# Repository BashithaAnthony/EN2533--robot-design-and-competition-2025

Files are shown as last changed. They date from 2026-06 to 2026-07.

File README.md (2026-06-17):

# EN2533 – Robot Design and Competition 2025

## Overview

As my first complete robotics project, this robot was designed from the ground up to autonomously navigate a multi-stage competition arena, perform object manipulation tasks, interpret environmental information, and complete a series of engineering challenges without human intervention.

The project required the integration of mechanical design, embedded systems, sensor fusion, control systems, and autonomous decision-making into a single robotic platform capable of completing all competition tasks reliably and efficiently.

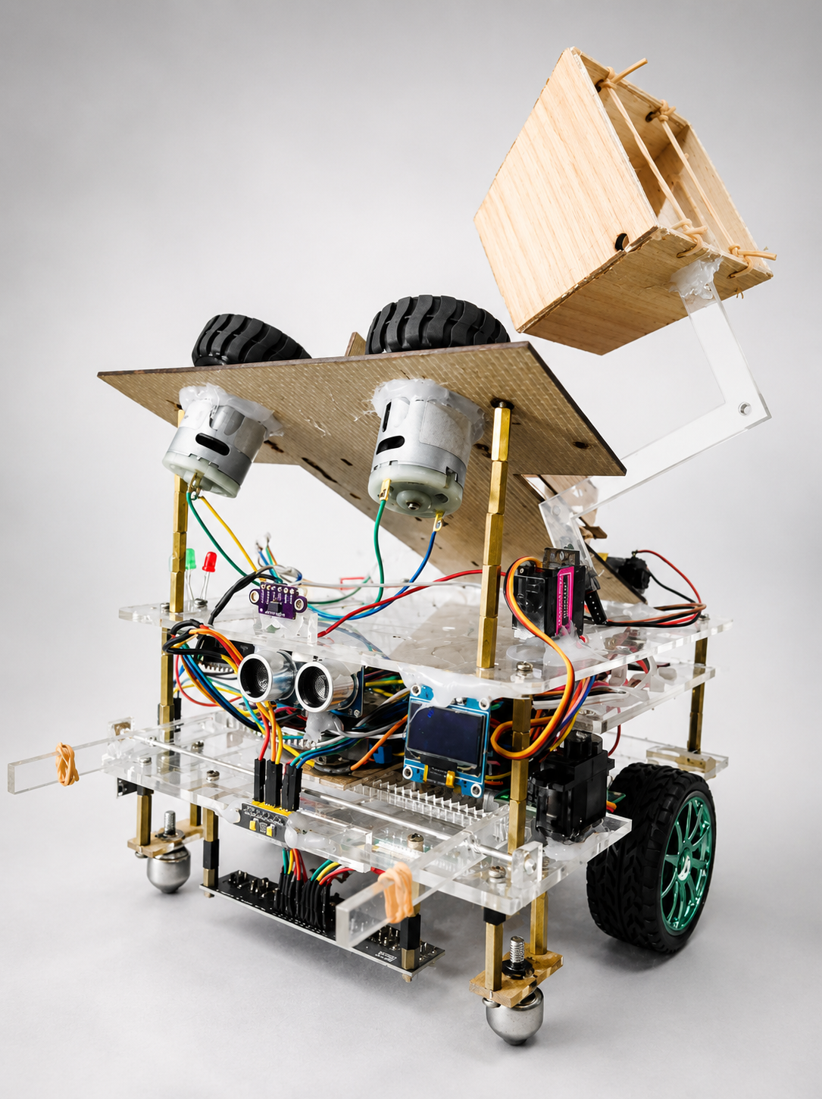
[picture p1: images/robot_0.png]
Robot Overview


## Competition Tasks

The robot was designed to complete the following six autonomous challenges:

### 1. Grid Navigation and Box Pick-and-Place
- Navigate a structured grid environment.
- Identify target locations.
- Pick up and transport boxes.
- Place objects accurately at designated positions.

### 2. Ramp Alignment, Ascending and Descending
- Set up the ramp.
- Maintain stability while climbing.
- Perform controlled descent without losing localization.

### 3. Barcode Reading
- Detect and scan barcodes placed on the arena floor.
- Decode barcode information.
- Use the extracted information for next task execution.

### 4. Circular Wall Following and Ball Collection
- Follow a circular wall using distance sensing.
- Maintain a consistent offset from the wall.
- Locate and collect balls while following the inner circular wall

### 5. Dashed Line Following and Pendulum Crossing
- Detect and follow discontinuous line markings.
- Handle temporary loss of line information.
- Safely navigate through a moving pendulum obstacle.

### 6. Ball Shooting Mechanism
- Position accurately at the target zone.
- Aim and launch collected balls toward designated targets.

## Hardware Components

### Main Controller
- Arduino Mega 2560

### Actuation Systems
- DC Motors with Quadrature Encoders
- Stepper Motors
- Servo Motors

### Sensors
- Time-of-Flight (ToF) Distance Sensors
- Ultrasonic Sensors
- Infrared (IR) Sensors
- Color Sensors

## Technical Highlights

- Fully autonomous operation
- Multi-sensor integration and sensor fusion
- Encoder-based motion control
- Closed-loop navigation
- Autonomous object manipulation
- Real-time obstacle detection and avoidance
- Modular software architecture
- Embedded control system development
- Mechanical system design and fabrication

## Project Status

Completed

Developed as part of the **EN2533 – Robot Design and Competition** module and demonstrated in the final competition environment.

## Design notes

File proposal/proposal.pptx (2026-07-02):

## EN2533 - Robot presentation

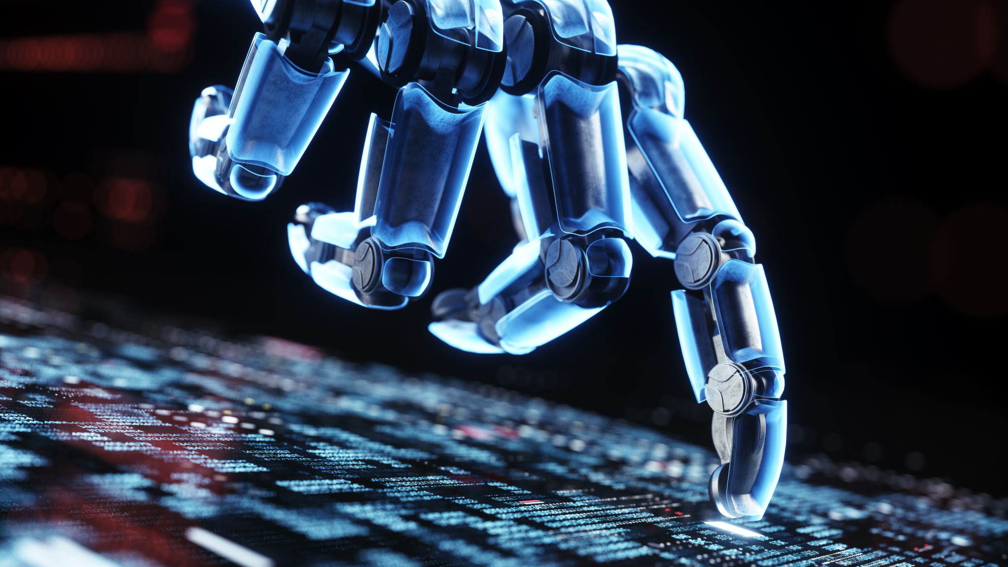
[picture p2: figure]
Robot operating a machine

TEAM HELABOTS

230045X

230140J

230697V

230730T

Anthony C.S.B.

Dharmakeerthi P.K.G.C.L.

Weerasinghe J.A.H.R.

Wijethilaka J.S.

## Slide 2

Timeline

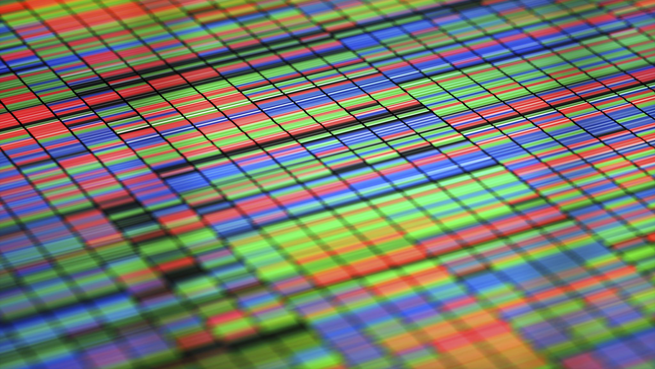
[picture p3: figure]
Vibrant multicolor checkered floor design

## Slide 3

September | | | | October
Week 1 | Week 2 | Week 3 | Week 4 | Week 5 | Week 6 | Week 7 | Week 8
Task Identification, Initial Designs | Component selection, Purchasing components | Preparation for assignment and Task evaluation | Initial Assembling | Coding and Testing | | Finalizing Assembling of the Robot

November | | | | December
Week 9 | Week 10 | Week 11 | Week 12 | Week 13 | Week 14 | Week 15 | Week 16
Preparation for mid evaluation | End Semester Examinations | | | Calibration, Testing and Debugging | | | Robot Competition

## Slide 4

Task 1 - The Labyrinth of Shadows

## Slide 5

PATH FINDING

- The robot will be placed at the position Po and it will start traversing the grid to P1 avoiding all obstacles it encounter.
- Then it will start travelling to P2 while scanning the destinations where the boxes should be placed and mapping them.
- Thereon from P2 the robot will start solving the grid while avoiding obstacles.
- When the robot encounters a box, it will grab it and start travelling to the appropriate destination through shortest available path.

- If an obstacle is encountered while travelling to the destination, the robot will map it and start travelling to the destination through the shortest path without the obstacle.

- After travelling it will drop the box there and continue travelling the grid until two boxes are placed on their respective destinations.

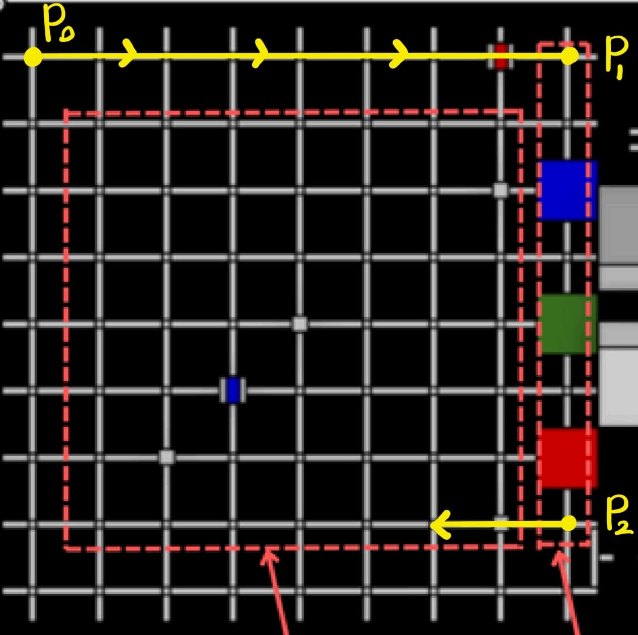
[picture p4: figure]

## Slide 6

LINE FOLLOWING

- We chose the MD0167 8-Bit Line Hunting Sensor Follower Module for line following because of its,
- Wide Detection Range
  - The module has 8 independent IR sensors arranged in a row, which provides much better coverage compared to single-sensor or 3-sensor modules.
- High Precision and Stability
  - With 8 channels, it allows fine resolution in detecting the line’s exact position.
- Simple Integration with Arduino
  - It’s fully compatible with Arduino and other microcontrollers.
- Better Performance on Different Surfaces
  - The MD0167 has built-in sensitivity adjustment, so it works well on surfaces with varying reflectivity.
- Cost-Effectiveness

8-Bit Line Hunting Sensor Follower Module for Arduino (MD0167)

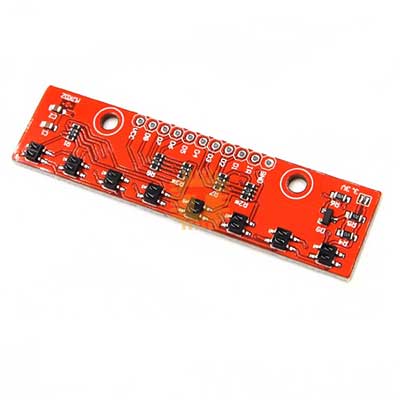
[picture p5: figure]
A red circuit board with black and red components

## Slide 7

BOX DETECTION

- We chose the HY-SRF05 Ultrasonic Sensor for obstacle and box detection and to differentiate between the boxes and the obstacles TCS34725 RGB Colour Recognition Sensor is used as boxes have their specific RGB colours.
- The HY-SRF05 Ultrasonic Sensor can measure distances from about 2 cm up to 4–5 meters with good accuracy. Compared to the common HC-SR04 sensor, the HY-SRF05 has better accuracy and stability in distance measurement. So, it provides accurate distance measurements. Also it is easy to interface with Arduino. Since it uses ultrasonic sound waves, it works equally well in dark or bright environments where optical sensors might fail.
- The TCS34725 has a high-quality RGB and clear light sensing photodiode array. The sensor includes an IR blocking filter, which removes infrared light interference. This makes color detection more accurate even under different lighting conditions. This also is well supported with Arduino libraries.

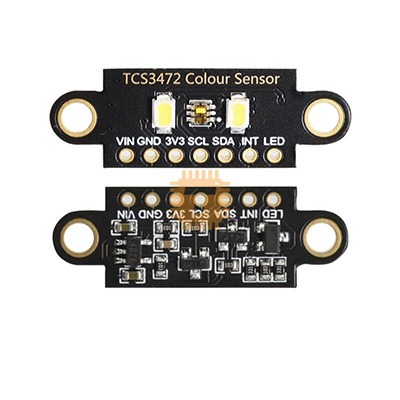
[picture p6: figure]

TCS34725 RGB colour Recognition sensor

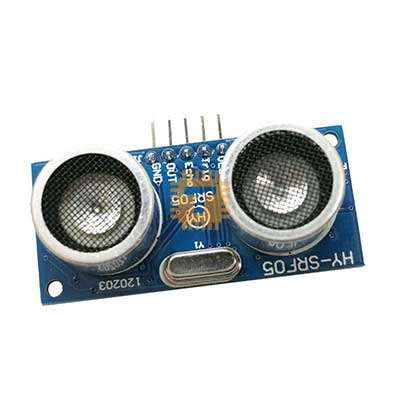
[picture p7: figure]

HY-SRF05 HC-SR05 5Pin Ultrasonic Sensor Module

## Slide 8

BOX PICKING & PLACING

- The boxes are picked from robot arm mechanism powered by MG90 Metal Wheel Servo Motor.

Why We Chose the MG90 Metal Gear Servo Motor

- High Torque for Small Size
  - The MG90 provides around 2.2 kgcm torque, which is enough to move lightweight robotic arms and small payloads.
- Metal Gears for Durability
  - Unlike plastic gear servos (e.g., SG90), the MG90 uses metal gears, making it more durable. This makes it suitable for repeated arm movements without gear damage.
- Arduino Friendly
  - Works easily with Arduino PWM libraries.

Servo Motor Metal Wheel MG90

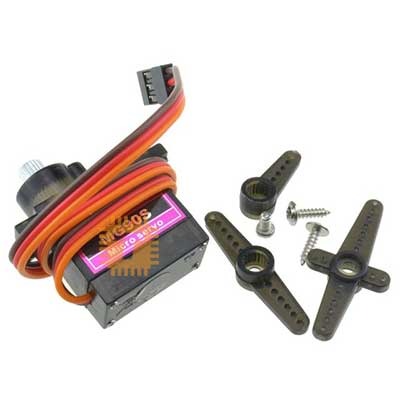
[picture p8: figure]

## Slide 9

Task 2 – The Ramp of Trials

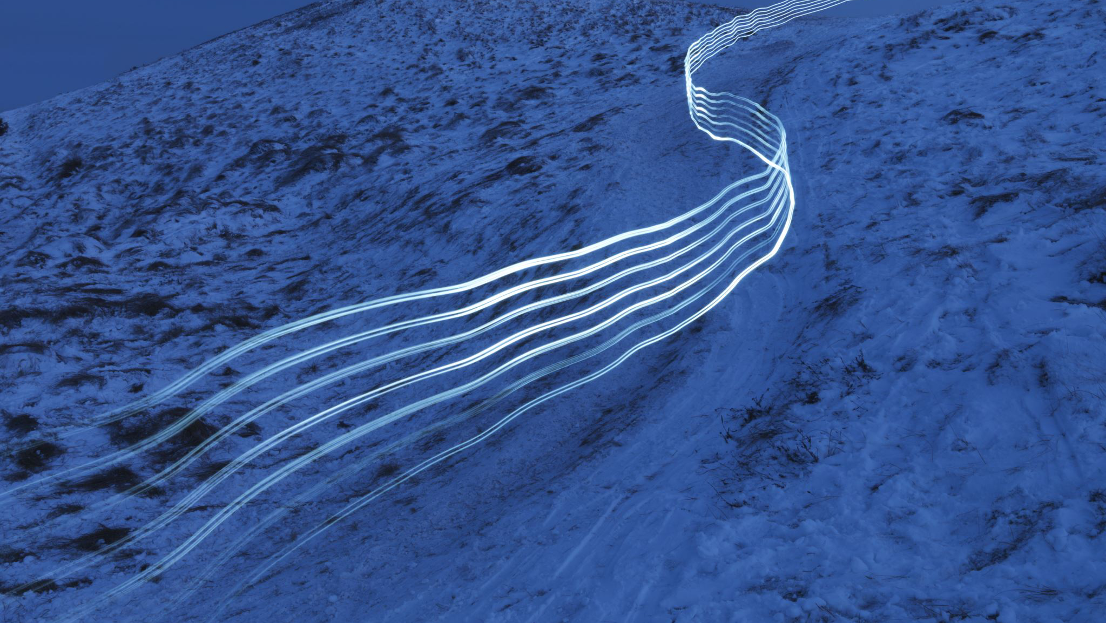
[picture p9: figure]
Smoke pattern on snow

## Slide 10

- In this task the robot will traverse through the broken lines using the IR sensor array until it finds a horizontal line and stop there.
- Using the closed front arms, it will push the box and fill the gap.
- Then the robot will comeback to the position of the horizontal line.
- After that the robot will traverse back to the starting point of the broken lines following the broken lines.
- Then it will approach the ramp and climb up and down the ramp.
- When climbing up, robot arm will be stretched towards the frontside of the robot (towards the ramp) and while climbing down, arm will be stretched towards the backside of the robot to keep the center of the gravity at a better position.

Traversing the broken lines:
The robot follow the direction of each line segment until it find the next line segment and then it will adjust the direction again.

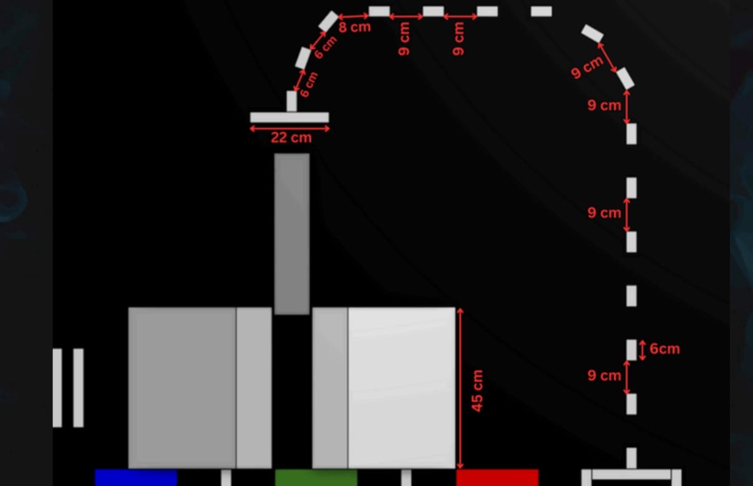
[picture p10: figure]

## Task 3 – the oracle of runes

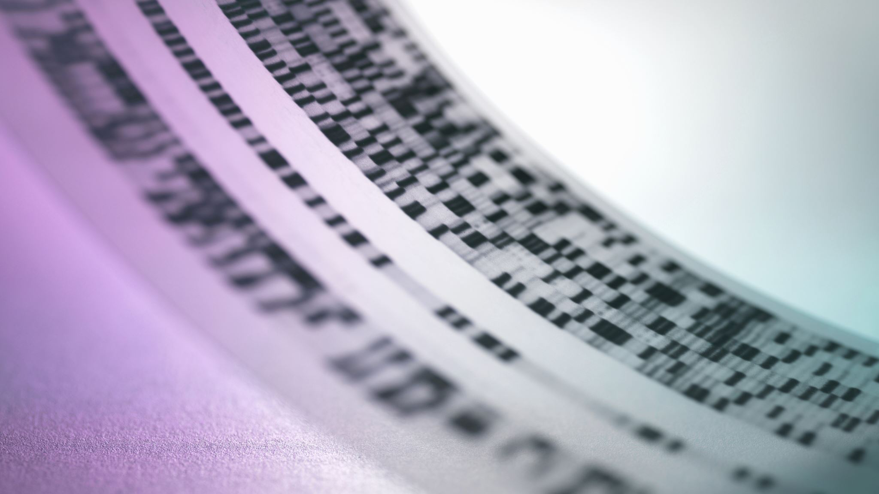
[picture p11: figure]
Autoradiogram on white paper

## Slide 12

- In the oracle of runes, the robot will come to the barcode area, and it will pass through the barcode at a constant speed while measuring the time to pass the white lines separately.

- Then it will decode the barcode and read the number and divide it by 3 and take the remainder.
- This will tell us the number of spheres we have to collect which will be one of 2,3 or 4 spheres.

- The robot will have 4 indicating LEDs to light up accordingly to show the number of spheres it should collect.

Remainder | No. of Spheres | No. of LEDs Turned on
0 | 2 | 2
1 | 3 | 3
2 | 4 | 4

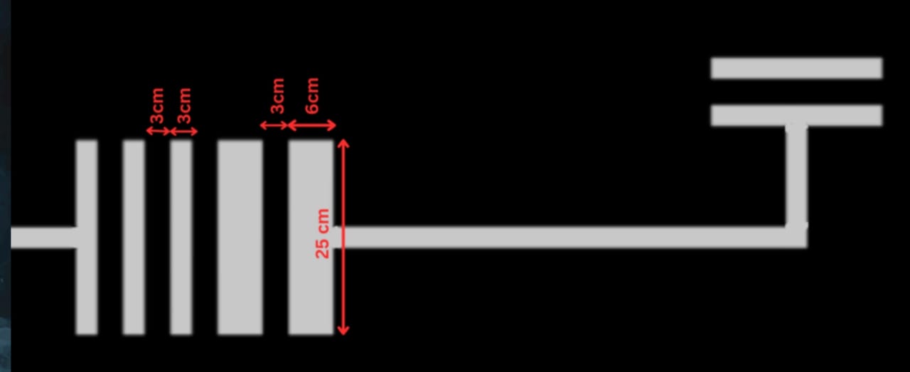
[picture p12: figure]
A white rectangular object with red text

## Task 4 – the circular fortress

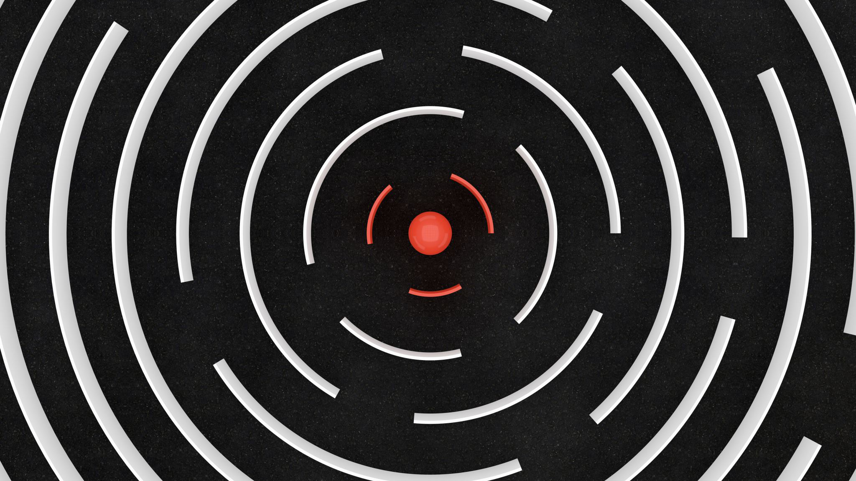
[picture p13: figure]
Top view of a labyrinth

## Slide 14

- The robot moves forward until it reaches a wall.
- Then follows the wall while maintaining a constant distance from it until it detects an opening.
- After detecting the opening, the robot makes a 180- degree U turn around the corner of the opening and continues following the wall while using its robotic arm to pick up balls and place them into a container.
- Once it reaches the opposite end, it performs another 180-degree turn around the other corner and returns to the starting position by following the wall.

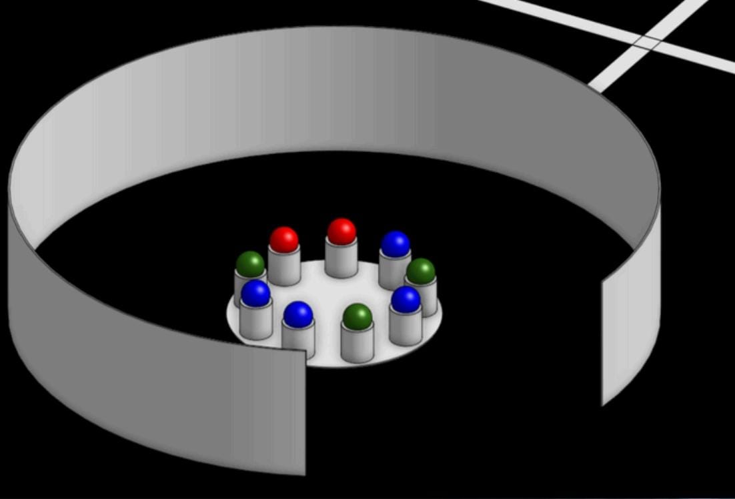
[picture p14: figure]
A circular object with several colored objects

## Task 5 – the wall of whispers & pendulum of doom

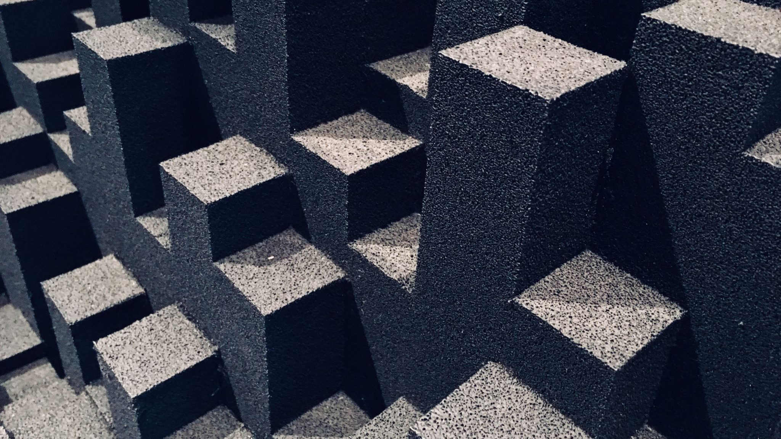
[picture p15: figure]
3D square and rectangle

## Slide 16

- This task consists of 3 major phases.
  1. Traversing the broken lines
  2. THE HIDDEN TASK
  3. Wall following & avoiding the pendulum

1.Traversing the broken
lines using IR sensor array:
Robot follow the direction of each line segment until it find the next line segment and then it will adjust the direction again.

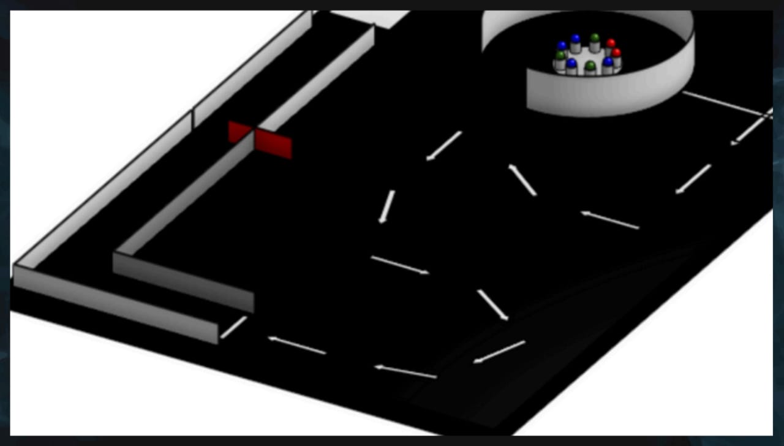
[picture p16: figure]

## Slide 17

2. Wall Following & Avoiding the Pendulum:
Using 2 Time of Flight sensors at two sides of the robot, it will go through two walls at a medium speed until it reaches the first junction and then it will move little bit slower until it detects the pendulum. Right after pendulum swings away, robot will move fast towards forward direction.

- After coming towards the end of two walls, robot will end up staying on the white square with the aid of IR sensors. After correctly positioning the robot on the square, it will turn left towards the ring of triumph.

## Task 6 – the line of destiny & the ring of triumph

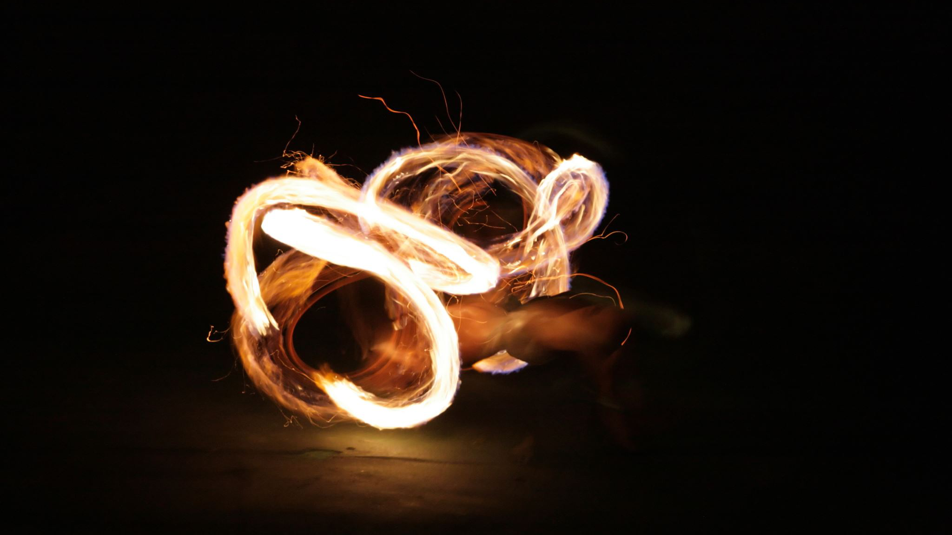
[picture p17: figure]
A light trail using fire

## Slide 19

- In this task we will try out 2 methods.

1. Method 01:
  - Balls will be shot towards the ring using two rotating motors. Using the mechanical arm, balls will be placed right in the middle of two motors.

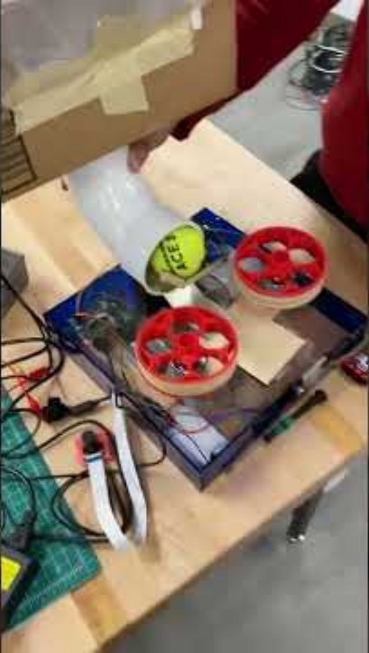
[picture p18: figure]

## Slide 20

2. Method 02:
  - Balls will be shot using a triggering mechanism as follows. In this method, there will not be any need to place the ball again because, after picking balls, they will be stored in the container where the triggering mechanism is connected right beneath the container

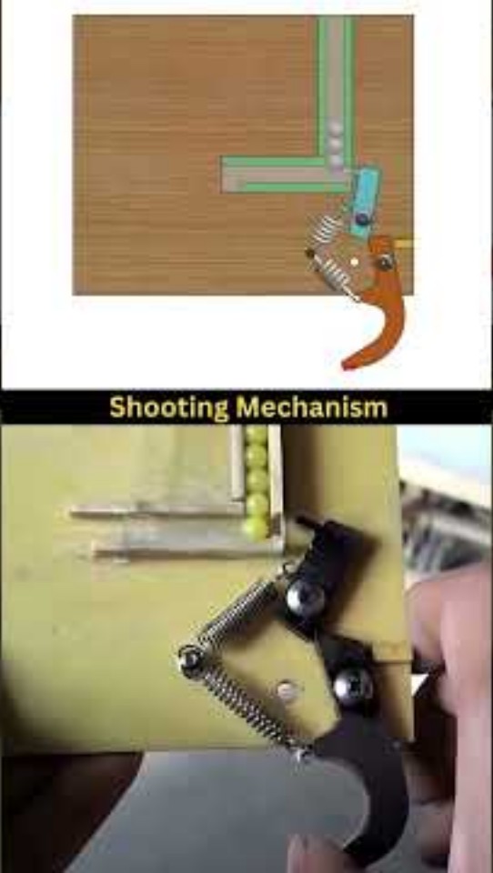
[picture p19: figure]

## The Budget

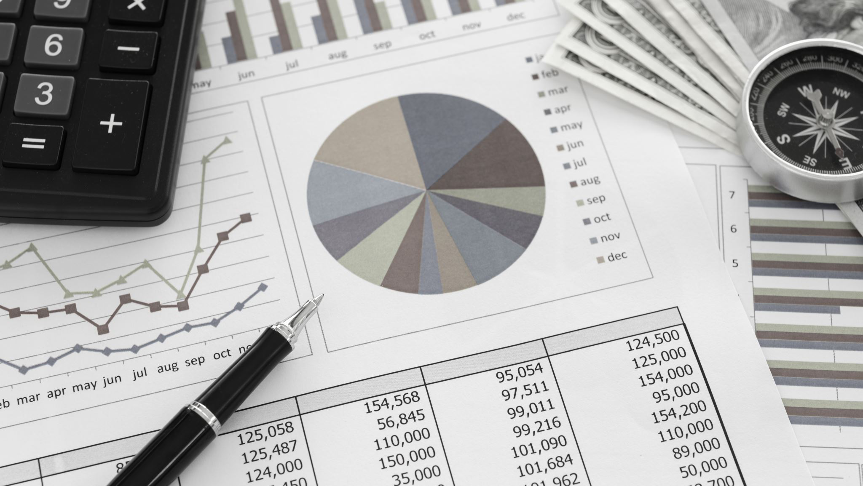
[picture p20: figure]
Calculator, pen, compass, money and a paper with graphs printed on it

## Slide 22

Component | Quantity | Unit Price (LKR) | Total (LKR)
Encoder motors | 2 | 3400 | 6800
Wheels | 2 | 100 | 200
Encoder motor driver | 1 | 320 | 320
Servo motors | 5 | 480 | 2400
Colour sensors | 3 | 760 | 2280
Buck converter | 1 | 180 | 180
Arduino mega | 1 | 4850 | 4850
Acrylic board | 1 | 1650 | 1650
IR sensor array | 1 | 480 | 480
ToF sensors | 3 | 600 | 1800
11.1V LiPo battery | 1 | 3000 | 3000
11.1V LiPo battery charger | 1 | 2500 | 2500
Ultrasonic sensor | 1 | 390 | 390
Robot arms (Materials, Laser cutting, 3D printing) | | | 3500
16 channel analog multiplexer | 1 | 450 | 450
Others | | | 750
Total | | | 31550

## Q&A

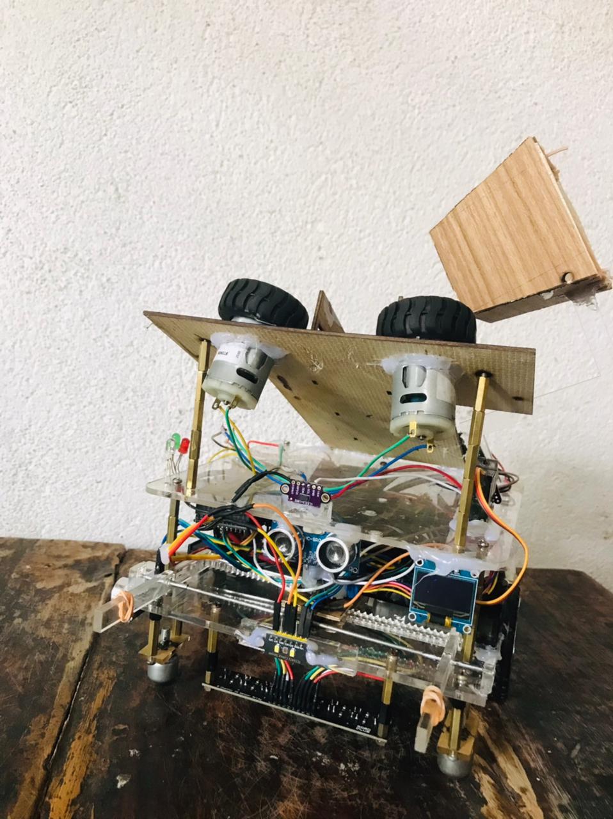
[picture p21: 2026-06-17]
images/robot_2.jpeg

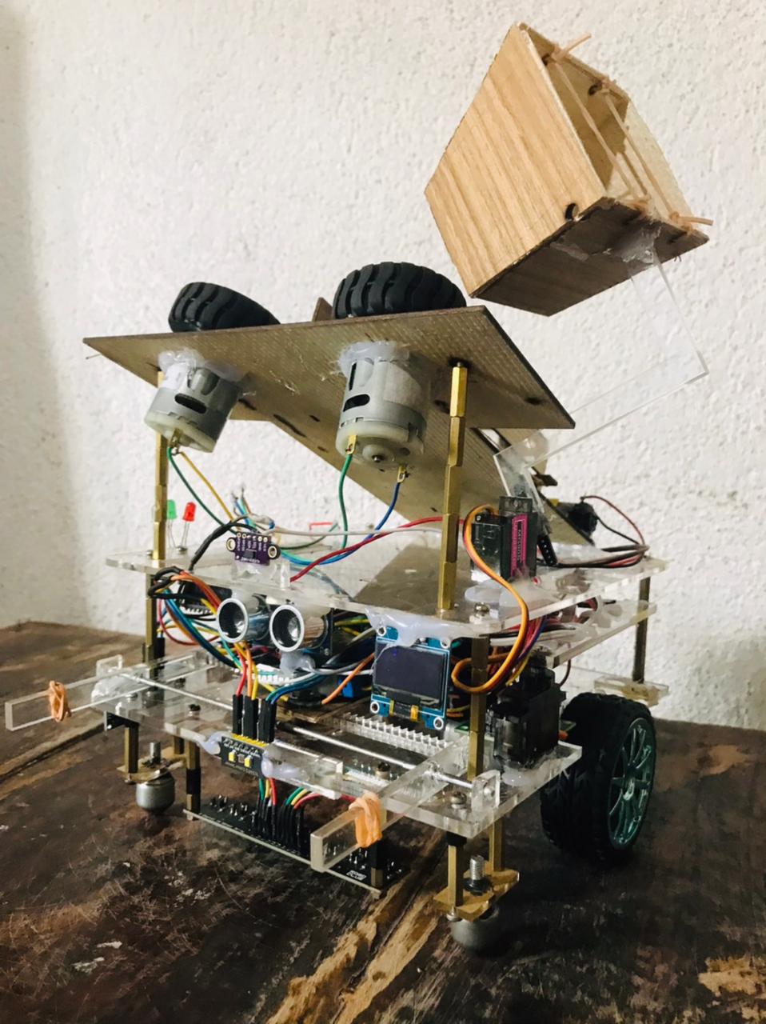
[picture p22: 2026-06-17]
images/robot_1.jpeg

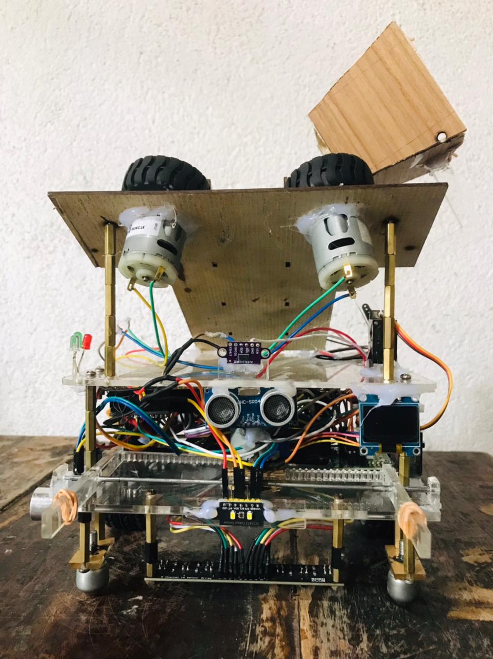
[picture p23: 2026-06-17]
images/robot_front.jpeg

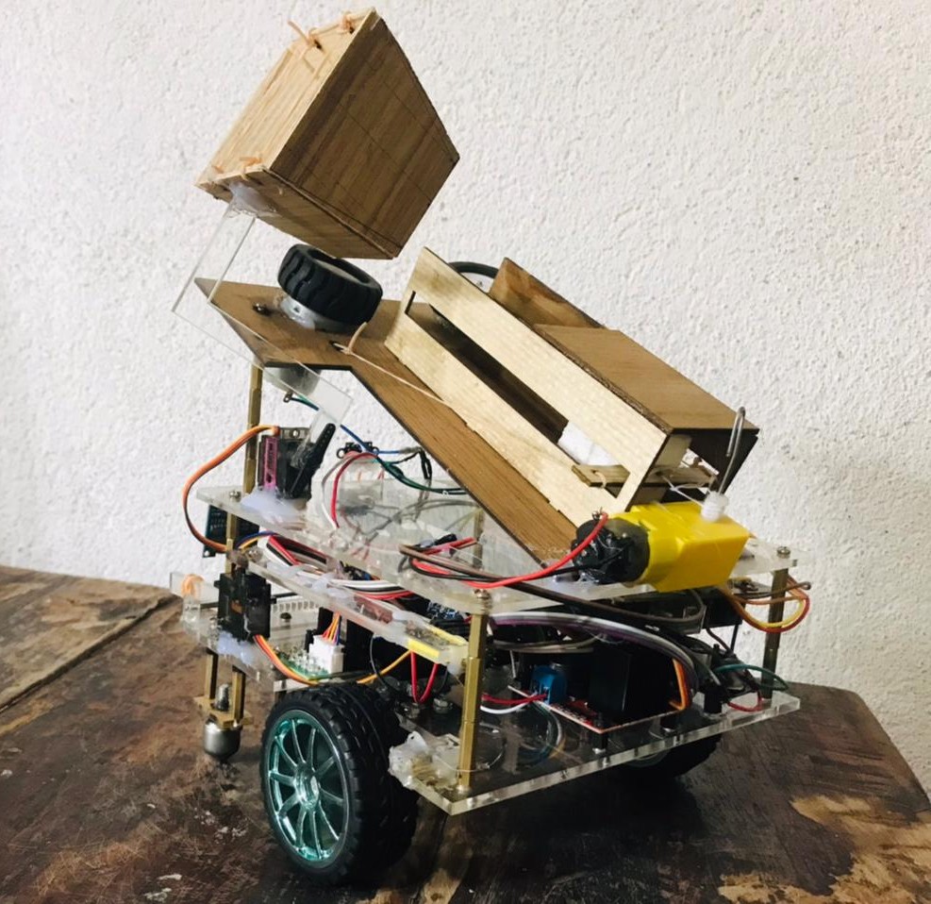
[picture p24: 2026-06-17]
images/robot_back.jpeg

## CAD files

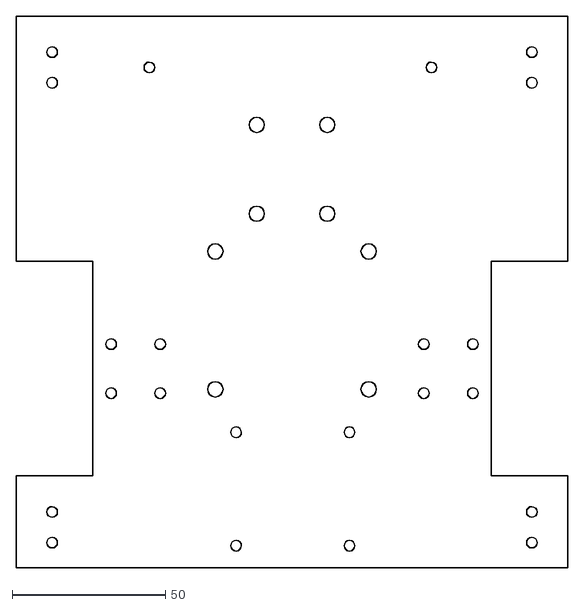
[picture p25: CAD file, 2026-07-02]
design_files/robot_platform.dxf
180.0 x 180.0

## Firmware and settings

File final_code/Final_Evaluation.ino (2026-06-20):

//--Colour Sensor and two ToF sensors--//
#include <Wire.h>
#include <VL53L0X.h>
#include <Adafruit_VL53L0X.h>
#include "Adafruit_TCS34725.h"
#include <Servo.h>
#include <Adafruit_GFX.h>
#include <Adafruit_SSD1306.h>
#include "I2Cdev.h"
#include "MPU6050_6Axis_MotionApps20.h"

//Varibles for Menu handaling
#define BUTTON_PIN 34
bool button_pushed = true;
int8_t task = 1;

//Display Object
Adafruit_SSD1306 display(128, 64, &Wire, -1);
#define SCREEN_WIDTH 128
#define SCREEN_HEIGHT 64
#define OLED_ADDR 0x3C


Servo servo1; // Colour Sensing Servo
Servo servo2; // Ball Picking Servo

//VL53L0X tof1;   // ToF on channel 5
//VL53L0X tof2;   // ToF on channel 4
// ---------- ToF SENSORS ----------
Adafruit_VL53L0X tof1;  // CH4
Adafruit_VL53L0X tof2;  // CH5

Adafruit_TCS34725 colorSensor = Adafruit_TCS34725(
  TCS34725_INTEGRATIONTIME_50MS,
  TCS34725_GAIN_4X
);

// ---------- COLOR SENSORS ----------
Adafruit_TCS34725 color1 = Adafruit_TCS34725(
  TCS34725_INTEGRATIONTIME_50MS, TCS34725_GAIN_4X);  // CH3

Adafruit_TCS34725 color2 = Adafruit_TCS34725(
  TCS34725_INTEGRATIONTIME_50MS, TCS34725_GAIN_4X);  // CH7

uint16_t dist1 = 0;
uint16_t dist2 = 0;


//------BFS parameters-----//

struct Node{
  int8_t x;
  int8_t y;
};

struct direction{
  int8_t delta_x;
  int8_t delta_y;
};

enum node_state{
  Free,
  NotKnow,
  Blocked,
  Box
};

node_state grid[9][9] = {
  {NotKnow, NotKnow, NotKnow, NotKnow, NotKnow, NotKnow, NotKnow, NotKnow, NotKnow},
  {NotKnow, NotKnow, NotKnow, NotKnow, NotKnow, NotKnow, NotKnow, NotKnow, NotKnow},
  {NotKnow, NotKnow, NotKnow, NotKnow, NotKnow, NotKnow, NotKnow, NotKnow, NotKnow},
  {NotKnow, NotKnow, NotKnow, NotKnow, NotKnow, NotKnow, NotKnow, NotKnow, NotKnow},
  {NotKnow, NotKnow, NotKnow, NotKnow, NotKnow, NotKnow, NotKnow, NotKnow, NotKnow},
  {NotKnow, NotKnow, NotKnow, NotKnow, NotKnow, NotKnow, NotKnow, NotKnow, NotKnow},
  {NotKnow, NotKnow, NotKnow, NotKnow, NotKnow, NotKnow, NotKnow, NotKnow, NotKnow},
  {NotKnow, NotKnow, NotKnow, NotKnow, NotKnow, NotKnow, NotKnow, NotKnow, NotKnow},
  {Blocked, Blocked, Blocked, Blocked, Blocked, Blocked, Blocked, Blocked, Blocked}
};

const direction directions[4] = { {0,1}, {0,-1}, {1,0}, {-1,0}}; // North, South, East, West

const Node Search_path[81] = {
  {0,0}, {1,0}, {2,0}, {3,0}, {4,0}, {5,0}, {6,0}, {7,0}, {8,0},
  {8,1}, {7,1}, {6,1}, {5,1}, {4,1}, {3,1}, {2,1}, {1,1}, {0,1},
  {0,2}, {1,2}, {2,2}, {3,2}, {4,2}, {5,2}, {6,2}, {7,2}, {8,2},
  {8,3}, {7,3}, {6,3}, {5,3}, {4,3}, {3,3}, {2,3}, {1,3}, {0,3},
  {0,4}, {1,4}, {2,4}, {3,4}, {4,4}, {5,4}, {6,4}, {7,4}, {8,4},
  {8,5}, {7,5}, {6,5}, {5,5}, {4,5}, {3,5}, {2,5}, {1,5}, {0,5},
  {0,6}, {1,6}, {2,6}, {3,6}, {4,6}, {5,6}, {6,6}, {7,6}, {8,6},
  {8,7}, {7,7}, {6,7}, {5,7}, {4,7}, {3,7}, {2,7}, {1,7}, {0,7},
  {0,8}, {1,8}, {2,8}, {3,8}, {4,8}, {5,8}, {6,8}, {7,8}, {8,8}
};

int currentpoint_index = 0;
int nextpoint_index = 1;
direction current_direction = {0,1};
Node current_Node;
Node next_Node;
Node next_NodeTemp;
int8_t dx = 0;
int8_t dy = 0;
int8_t new_des_index;
Node new_destination_node;
bool going_recalculated_path = false;

//---Constructing que for path node que---//
const int MAX_Q = 81;  // max queue size
Node path_node_que[MAX_Q] = {{0,0}, {1,0}};

int front = 0;
int rear = 2;
int count = 2;

Node path_out[81];

const int8_t dirs[4][2] = {
  { 1, 0 },
  { -1, 0 },
  { 0, 1 },
  { 0, -1 }
};



#define TCA_ADDR 0x70

//Select multiplexer channel 
void tcaSelect(uint8_t channel) {
  Wire.beginTransmission(TCA_ADDR);
  Wire.write(1 << channel);
  Wire.endTransmission();
}


//Ramp
MPU6050 mpu;

// ---- DMP variables ----
bool dmpReady = false;
uint8_t fifoBuffer[64];
Quaternion q;
VectorFloat gravity;
float ypr[3];

float roll = 0; 
float pitch = 0;
float yaw = 0;

unsigned long startTime = 0;


/* --- IR SENSOR ARRAY PINS --- */
const int irPins[8] = {A0, A1, A2, A3, A4, A5, A6, A7};
const int Weight[8] = {0, 2000, 3000, 4000, 5000, 6000, 7000, 9000};
int sensor[8];
long total = 0;
long weightedSum = 0;

/* ---Control 28BYJ-48 Stepper by Desired Angle--- */

// ULN2003 Pins
const int IN1 = 33;
const int IN2 = 35;
const int IN3 = 37;
const int IN4 = 39;
float stepDelay = 2;  // speed (ms) smaller = faster
int stepIndex = 0;

// 4-step sequence for 28BYJ-48
int stepSequence[4][4] = {
  {1, 0, 0, 0},
  {0, 1, 0, 0},
  {0, 0, 1, 0},
  {0, 0, 0, 1}
};


/* ---Colour Sensor--- */
String colour = "None";
String neededColour = "None";

//---Ultrasonic sensor parameters---//
long ultra_duration =0;
long ultra_distance = 0;
#define trigPin  51
#define echoPin  49



// SIDE ULTRASONIC PINS
// -------------------------
#define TRIG_PIN 12   
#define ECHO_PIN 11   


#define AIN1 47
#define AIN2 45
#define PWMA 10   // Left motor PWM

#define BIN1 43
#define BIN2 41
#define PWMB 13   // Right motor PWM

#define STBY 26   // Standby pin

#define CIN1 28
#define CIN2 32
#define CPWM_PIN 6  

int juncDetected = 0;
int limit = 0;

/* --- MOTOR PINS (YOUR EXACT PINS) --- */

// Motor 1 (LEFT)
const int M1_PWM = 4;
const int M1_IN1 = 25;
const int M1_IN2 = 31;

// Motor 2 (RIGHT)
const int M2_PWM = 5;
const int M2_IN1 = 27;
const int M2_IN2 = 29;

// ===== ENCODER PINS =====
const int ENC_LEFT = 2; 
const int ENC_RIGHT = 19;

const int TRIG_PIN1 = 51;
const int ECHO_PIN1 = 49;

volatile long leftCount = 0;
volatile long rightCount = 0;
volatile long mediancount = 0;

const int PPR = 220 ;
const float WHEEL_DIAMETER = 0.065;
const float WHEEL_BASE = 0.165;

float robotCircumference = 3.14159 * WHEEL_BASE;
float turnDistance = robotCircumference / 4.0;
float wheelCircumference = 3.14159 * WHEEL_DIAMETER;
long ticksPer90Turn = (long)((turnDistance / wheelCircumference) * PPR);
long ticksPer180Turn = (long)((turnDistance / wheelCircumference) * PPR * 2 );


// =================== BARCODE CONFIG ======================
float BIT_1_WIDTH_CM = 6.0;   // 6 cm white = "1"
float BIT_0_WIDTH_CM = 3.0;   // 3 cm white = "0"

float WIDTH_TOLERANCE = 0.40;   // ±40%

float cmPerTick = 0.09282;   

// ================== INTERNAL BARCODE STATE ===============

String barcode = "";


/* --- SPEED & PID CONSTANTS --- */
int baseSpeed = 0;
float Kp = 0.1;       
float Kd = 0.05;        

float lastError = 0;


/* Wave-scan state */
int waveState = 0;     // 0 = Right, 1 = Left
unsigned long waveTimer = 0;
int waveTurn = 0;     // turning offset
unsigned long sweepDuration = 300; // ms for each half-wave

/* Dashed Line Following PID */
float Kdp = 0.1, Kdi = 0.0001, Kdd = 0.3;
float d_error, d_prevError, d_integral, d_lastError;

int whiteFound = 0;



// ============================================
// ENHANCED CIRCULAR WALL FOLLOWING WITH PID
// ============================================

// Configuration Constants
const float WALL_RADIUS = 45.0;           // cm - radius of circular wall
const float DESIRED_DISTANCE = 20.0;      // cm - desired gap from wall
const float ROBOT_TRACK_WIDTH = 15.0;     // cm - distance between wheels (ADJUST TO YOUR ROBOT)


// Speed Settings
const int BASE_SPEED = 140;               // Base speed for wall following
const int MIN_SPEED = 80;                 // Minimum motor speed
const int MAX_SPEED = 255;                // Maximum motor speed
const int BLIND_MODE_SPEED = 110;         // Speed when ultrasonic lost

// Ultrasonic Filtering
const int FILTER_WINDOW = 5;              // Moving average window
const float MAX_VALID_DISTANCE = 30.0;    // cm - max valid reading
const float MIN_VALID_DISTANCE = 5.0;     // cm - min valid reading

// Circular Path Calculation
//const float TURN_RATE_CIRCULAR = calculateCircularTurnRate();

// State Variables
float distanceBuffer[FILTER_WINDOW] = {0};
int bufferIndex = 0;

unsigned long lastValidReading = 0;
const unsigned long BLIND_MODE_TIMEOUT = 2000; // ms - how long to run blind
bool isInBlindMode = false;
float lastValidDistance = DESIRED_DISTANCE;

// Derivative filter (reduce noise)
float previousDerivative = 0;
const float DERIVATIVE_FILTER = 0.3;  // Low-pass filter coefficient

int Red = 0;
int Blue = 0;
int Green = 0;

// Create one VL53L0X object and reuse it for each channel
Adafruit_VL53L0X tof = Adafruit_VL53L0X();


void setup() {
  Serial.begin(115200);
  pinMode(BUTTON_PIN, INPUT_PULLUP);

  pinMode(trigPin, OUTPUT);
  pinMode(echoPin, INPUT);

  pinMode(CIN1, OUTPUT);
  pinMode(CIN2, OUTPUT);
  pinMode(CPWM_PIN, OUTPUT);

  pinMode(AIN1, OUTPUT);
  pinMode(AIN2, OUTPUT);
  pinMode(PWMA, OUTPUT);

  pinMode(BIN1, OUTPUT);
  pinMode(BIN2, OUTPUT);
  pinMode(PWMB, OUTPUT);

  pinMode(STBY, OUTPUT);

  // Wake up the driver
  digitalWrite(STBY, LOW); 

  pinMode(TRIG_PIN, OUTPUT);
  pinMode(ECHO_PIN, INPUT);

  // Motor pins
  pinMode(M1_PWM, OUTPUT);
  pinMode(M1_IN1, OUTPUT);
  pinMode(M1_IN2, OUTPUT);

  pinMode(M2_PWM, OUTPUT);
  pinMode(M2_IN1, OUTPUT);
  pinMode(M2_IN2, OUTPUT);

  // Encoder pins
  pinMode(ENC_LEFT, INPUT_PULLUP);
  pinMode(ENC_RIGHT, INPUT_PULLUP);

  attachInterrupt(digitalPinToInterrupt(ENC_LEFT), leftEncoderISR, RISING);
  attachInterrupt(digitalPinToInterrupt(ENC_RIGHT), rightEncoderISR, RISING);

  pinMode(IN1, OUTPUT);
  pinMode(IN2, OUTPUT);
  pinMode(IN3, OUTPUT);
  pinMode(IN4, OUTPUT);

  //LED pins
  pinMode(42,OUTPUT);
  pinMode(46,OUTPUT);
  pinMode(50,OUTPUT);

  Wire.begin();
  Wire.setClock(100000); // 100kHz for stability

  // ---------------- Color 1 (CH 3) ----------------
  tcaSelect(3);
  if (!color1.begin()) {
    Serial.println("❌ Color Sensor 1 (CH3) NOT FOUND!");
  } else {
    Serial.println("✅ Color Sensor 1 (CH3) detected!");
  }
  delay(100);

  //---OLED Display----//
  tcaSelect(4);

  display.begin(SSD1306_SWITCHCAPVCC, OLED_ADDR);
  



  // ------ Colour sensor on CH7 ------
  tcaSelect(7);
  if (!colorSensor.begin()) {
    Serial.println("ERROR: Colour sensor (CH7) NOT FOUND!");
  } 
  else {
    Serial.println("Colour Sensor Ready on CH7");
  }
  delay(100);
  Serial.println("All sensors initialized!");



  // ---------------- ToF A (CH2) ----------------
  tcaSelect(2);
  if (!tof.begin()) Serial.println("❌ ToF_A (CH2) NOT FOUND!");
  else Serial.println("✅ ToF_A (CH2) detected!");


  /*servo1.attach(8);     // First servo on pin 8 - Colour Sensing
  servo2.attach(7);     // Second servo on pin 7 - Ball Picking
  servo1.write(60);     // Start at center
  servo2.write(0);     // Start at center
  delay(500);

  servo1.detach();
  servo2.detach();*/

  //initialize disply
  display.begin(SSD1306_SWITCHCAPVCC, 0x3C);
  display.clearDisplay();
  display.display();

  delay(1000);
}

void loop() {

  if (digitalRead(BUTTON_PIN)==LOW && !button_pushed){
    button_pushed = true;
    delay(200);
  }
  if (button_pushed){
    leftCount=1;
    while (true){
      if (leftCount>41){leftCount=1;}
      if (digitalRead(BUTTON_PIN) == LOW){
        button_pushed=false;
        delay(3000);
        break;
      }

      task = (leftCount/6) +1;
      showMenu(task);
      delay(80);

    }
  }
  else{showMenu(task);}

  if (task==1){
    /*-----Task 1-----*/

  // Grid Search

    /*gostraight(0,100);
    centerTheRobot(100);
    turn90Left();
    juncDetected = 0;
    while (juncDetected == 0) {
      linefollow(0,100);
    }
    centerTheRobot(100);
    turn90Right();
    gostraightTask1(0,-100);
    centerTheRobot(100);*/

    rotateAngle(400);
    current_Node = {0,0};

    for (int x = 0; x < 81; x++) {
      
      next_Node = Search_path[x];
      if (current_Node.x == next_Node.x && current_Node.y == next_Node.y) {
        continue;
        
      } else {

        while (grid[next_Node.x][next_Node.y] == NotKnow) {
          shortestPath9x9(current_Node, next_Node, grid, path_out);
          for (int i = 0; i < count; i++) {
            int index = (front + i) % MAX_Q;  // handle circular queue
            Serial.print("Node ");
            Serial.print(i);
            Serial.print(": x=");
            Serial.print(path_node_que[index].x);
            Serial.print(", y=");
            Serial.println(path_node_que[index].y);
          } 

          bool exitWhile = false;
          while ((current_Node.x != next_Node.x || current_Node.y != next_Node.y) && !exitWhile) {
            int length = count;
            for (int z = 0; z < count; z++) {
              next_NodeTemp = dequeue();
              

              if (grid[next_NodeTemp.x][next_NodeTemp.y] == NotKnow) {
                rotate(current_direction, current_Node, next_NodeTemp);
                ultra_distance = getDistance1();

                if (ultra_distance < 20) {
                  digitalWrite(42,HIGH);
                  delay(500);
                  digitalWrite(42,LOW);

                  int16_t d = readToF_mm(2);
                  if (d <= 250) {
                    grid[next_NodeTemp.x][next_NodeTemp.y] = Box;
                    digitalWrite(42,HIGH);
                    digitalWrite(46,HIGH);
                    digitalWrite(50,HIGH);
                    delay(500);
                    digitalWrite(42,LOW);
                    digitalWrite(46,LOW);
                    digitalWrite(50,LOW);
                  } else {
                    grid[next_NodeTemp.x][next_NodeTemp.y] = Blocked;
                    digitalWrite(42,HIGH);
                    delay(500);
                    digitalWrite(42,LOW);
                  }
                  gostraightTask1(0,-100);
                  centerTheRobot(100);
                  exitWhile = true;
                  
                  break;
                  
                } else {
                  while(juncDetected==0){linefollow(0,100);}
                  centerTheRobot(100);
                  grid[next_NodeTemp.x][next_NodeTemp.y] = Free;
                  current_Node = next_NodeTemp;
                  digitalWrite(46,HIGH);
                  delay(250);
                  digitalWrite(46,LOW);
                  Serial.print(current_Node.x);
                  Serial.print(",");
                  Serial.print(current_Node.y);
                  Serial.println();
                }
              }
              else { // If next_NodeTemp is FREE
                rotate(current_direction, current_Node, next_NodeTemp);
                while(juncDetected==0){linefollow(0,100);}
                current_Node = next_NodeTemp;
                digitalWrite(46,HIGH);
                delay(250);
                digitalWrite(46,LOW);
                centerTheRobot(100);
  
                Serial.print(current_Node.x);
                Serial.print(",");
                Serial.print(current_Node.y);
                Serial.println();
              }
              juncDetected=0;
            }
          }
        }
      }    
    }

    digitalWrite(50, HIGH);
    digitalWrite(42, HIGH);
    digitalWrite(46, HIGH);
    delay(1000);
    digitalWrite(50, LOW);
    digitalWrite(42, LOW);
    digitalWrite(46, LOW);

    // Box Placing

    for (int x = 0; x<9; x++) {
      for (int y = 0; y<9; y++) {
        if (grid[x][y] == Box) {
          shortestPath9x9(current_Node, {x,y}, grid, path_out);
          
          int length = count;
          for (int z = 0; z < (count - 1); z++) {
            next_NodeTemp = dequeue();
            rotate(current_direction, current_Node, next_NodeTemp);
            while(juncDetected==0){
              linefollow(0,100);
            }
            current_Node = next_NodeTemp;           
            centerTheRobot(100);
            juncDetected = 0;
          }
          next_NodeTemp = dequeue(); 
          rotate(current_direction, current_Node, next_NodeTemp);
          //current_Node = next_NodeTemp; 
          linefollow(0.07,100);
          colourSense1();

          if (colour == "Red") {
            Red = 1;
            shortestPath9x9(current_Node, {6,8}, grid, path_out);
            rotateAngle(-400);
          } else if (colour == "Blue") {
            Blue = 1;
            shortestPath9x9(current_Node, {2,8}, grid, path_out);
            rotateAngle(-400);
          } else if (colour == "Green") {
            Green = 1;
            shortestPath9x9(current_Node, {4,8}, grid, path_out);
            rotateAngle(-400);
          } else {
            continue;
          }


          gostraightTask1(0,-100);

          length = count;
          for (int z = 0; z < (count - 1); z++) {
            next_NodeTemp = dequeue();
            rotate(current_direction, current_Node, next_NodeTemp);
            while(juncDetected==0){
              linefollow(0,100);
            }
            current_Node = next_NodeTemp;           
            centerTheRobot(100);
            juncDetected = 0;
          }
          next_NodeTemp = dequeue();  
          rotate(current_direction, current_Node, next_NodeTemp);
          //current_Node = next_NodeTemp; 
          gostraight(0.1,100);
          rotateAngle(400);
          gostraight(0.1,-100);
          gostraightTask1(0,-100);
          centerTheRobot(100);

          
        }
      }
    }

    delay(500);
    
    if (Red == 0) {
      digitalWrite(42,HIGH);
      delay(2000);
      digitalWrite(42,LOW);
    } else if (Blue == 0) {
      digitalWrite(50,HIGH);
      delay(2000);
      digitalWrite(50,LOW);
    } else {
      digitalWrite(46,HIGH);
      delay(2000);
      digitalWrite(46,LOW);
    }
    //Ending the Task 1

    shortestPath9x9(current_Node, {8,8}, grid, path_out);
          
    int length = count;
    for (int z = 0; z < count; z++) {
      next_NodeTemp = dequeue();
      rotate(current_direction, current_Node, next_NodeTemp);
      while(juncDetected==0){
        linefollow(0,100);
      }
      current_Node = next_NodeTemp;           
      centerTheRobot(100);
      juncDetected = 0;
    }

    
    turn90Left();
    gostraight(0.05,100);
    turn90Right();
    gostraightTask1(0,-100);
    gostraight(0.04,100);
    task=2;

  }

  else if(task==2){
      /*-----Task 2-----*/

    // Dashed Line Following and Ramp Setting

    gostraight(0,100);
    centerTheRobot(100);

    juncDetected = 0;
    while (juncDetected == 0) {
      linefollowTask2(100,"Left");
    }
    gostraight(0.05,-120);
    turn180();
    gostraightTask1(0,-150);
    gostraight(0.2,-150);
    gostraight(0,120);
    centerTheRobot(100);

    juncDetected = 0;
    while (juncDetected == 0) {
      linefollowTask2(100,"Right");
    }

    gostraight(0.2, -150);
    turn90Left();
    
    
    //Ramp Climbing

    gostraight(0.35,-150);
    gostraight(0.1,-220);
    task=3;

  }
  else if(task==3){

      /*---- -Task 3------*/  

    //Align the robot with horizontal white stripes 
    gostraight(0,100);
    gostraight(0.3,100);

    juncDetected = 0;
    while (juncDetected == 0) {
      linefollowTask3(0,100);
    }
    centerTheRobot(100);
    turn90Right();

    // i. Entering The Barcode
    juncDetected = 0;
    while (juncDetected == 0) {
      linefollow(0, 100);
    }
    Serial.print("Linefollowing ended");
    Serial.println();
    delay(500);
    gostraight(0.1,-100);

    // ii. Barcode Reading
    if (juncDetected) {

      Serial.println("Straight white line ended!");
      Serial.println("Starting barcode scanning...");

      barcode = "";
      
      barcodeRead(0.6, 95);
      stopMotors();
      delay(500);
      Serial.print("FINAL BARCODE: ");
      Serial.println(barcode);

      int decodedNumber = 0;
      int barcodeLength = barcode.length();
      for (int i=0; i<barcodeLength; i++) {
        int digit = barcode[i] - '0';
        int x = 1 << (barcode.length() - (i+1)); // Multiplied by Powers of 2
        decodedNumber += digit * x ;
      }
      
      if (decodedNumber % 3 == 0) {
        //digitalWrite(42, HIGH);
        //delay(1000);
        //digitalWrite(42, LOW);
      } else if (decodedNumber % 3 == 1) {
        //digitalWrite(46, HIGH);
        //delay(1000);
        //digitalWrite(46, LOW);
      } else if (decodedNumber % 3 == 2) {
        //digitalWrite(50, HIGH);
        //delay(1000);
        //digitalWrite(50, LOW);
      } else {
        /*digitalWrite(42, HIGH); 
        digitalWrite(46, HIGH); 
        digitalWrite(50, HIGH); */
        //delay(2000);
        /*digitalWrite(42, LOW);
        digitalWrite(46, LOW); 
        digitalWrite(50, LOW);*/ 
      }
    }

    showNumberTwo();


    // iii. Exiting Task 3
    juncDetected = 0;
    while(juncDetected == 0) {
      linefollow(0,100);
    } 
    centerTheRobot(100);
    turn90Right();
    task=4;
  }
  
  else if(task==4){
    /*------Task 4------*/

    // Beginning - Before Circular Wall Following
    juncDetected = 0;
    linefollow(0.2,100);
    turn90Left();

    // 2. Outer Wall Following
    outerWallFollow(100,10,10);

    gostraight(0.2,100);
    turnAngleRight(30);
    delay(1000);
    gostraight(0.2,100);
    turn90Right();
    gostraight(0.3,100);
    turn90Right();
    


    // 3. Inner Wall Following 
    turnAngleRight(60);
    for (int x = 0; x < 7; x++) {
      if (x == 0) {
        turnAngleLeft(20);
      } else {
        gostraight(0.25,100);
        turnAngleLeft(50);
      }
    }


    // 4. End of Task 4
    outerWallFollow(100,10,10);
    centerTheRobot(100);
    turn90Left();
    juncDetected = 0;
    while (juncDetected == 0) {
      linefollow(0,120);
    }
    centerTheRobot(100);
    turn90Right();
    gostraightTask1(0,-120);
    centerTheRobot(100);
    task=5;
  }

  else if(task==5){
    /*------Task 5------*/

    //Dashed Line
    while (juncDetected == 0) {
      linefollowTask5(100); 
    }
    centerTheRobot(100);


    //Wall Following - 1st Half
    outerWallFollowTask5(100,4,4);
    gostraight(0.18, 100);
    turn90Right();

    //Wall Following - 2nd Half
    gostraight(0.1,100);
    outerWallFollowTask5(100,4,4);
    task=6;

  }
  else{
    /*------Task 6------*/

  gostraight(0,100);
  gostraight(0.25,100);
  delay(1000);

  //Shooting
  // ---- LEFT MOTOR (A output) Forward ----
  digitalWrite(STBY, HIGH);
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
